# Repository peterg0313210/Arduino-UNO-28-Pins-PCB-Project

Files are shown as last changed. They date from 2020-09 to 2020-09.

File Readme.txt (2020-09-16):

These two folders contain the manufacturing and assembly documentation I produced when I had my circuit board printed and assembled.
Some of the files might need to be downloaded to be viewed such as the Project_1.pdf file which shows the 3D model of my PCB on Adobe Reader. 
However, most of the files should be readily visible upon the initial click to view the file.

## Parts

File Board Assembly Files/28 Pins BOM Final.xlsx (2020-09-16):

 |  |  | Project 1 Arduino 28 Pins BOM
Item # | *Designator | *Qty | Manufacturer | *Mfg Part # | Description / Value | *Package/Footprint | Type | Your Instructions / Notes
1 | SCKT FOR U1 | 1 | 3M | 4828-3004-CP | CONN IC DIP SOCKET 28POS TIN | 28_DIP_7.62MM_ SOCKET | thru-hole
2 | J5, J6 | 2 | Amphenol FCI | 67997-106HLF | CONN HEADER 6POS .100 STR 30AU | HDR 2X3 | thru-hole
3 | JP1, JP4 | 2 | Amphenol FCI | 68000-103HLF | Conn Unshrouded Header HDR 3 POS 2.54mm Solder ST Thru-Hole Bulk | HEADER_1X3_2.54mm | thru-hole | JP4 is Non Fitted
4 | JP3 | 1 | Amphenol FCI | 68001-204HLF | CONN HEADER VERT 4POS 2.54MM | HEADER_1X4 | thru-hole
5 | JP2 | 1 | Amphenol FCI | 68602-204HLF | CONN HEADER VERT 4POS 2.54MM | HDR 2X2_2.54mm | thru-hole | JP2 is Non Fitted
6 | SW1, SW2 | 2 | TE Connectivity | 1825910-6 | Switch Push Button OFF (ON) SPST Round Button 0.05A 24VDC Momentary Contact PC Pins Thru-Hole | 1825910-6 | thru-hole
7 | J7 | 1 | Amphenol FCI | 10118193-0001LF | CONN USB MICRO B RECPT SMT R/A | USB_C | SMD
8 | D5, D6 | 2 | ON Semiconductor / Fairchild | BAT54HT1G | Small Signal Schottky Diode, Single, 30 V, 200 mA, 800 mV, 600 mA, 150 C ;RoHS Compliant: Yes | SOD323 | SMD
9 | Z1, Z2 | 2 | Bourns | CG0603MLC-05E | VARISTOR 0603 | R0603 | SMD
10 | D1 | 1 | Osram Opto | LGL29K-G2J1-24-Z | LED Uni-Color Green 572nm 2-Pin Chip 0603(1608Metric) T/R | LED_0603 | SMD
11 | R, T, U | 3 | Osram Opto | LOL29K-H2K1-24-Z | OSRAM - LO L29K-H2K1-24-Z - SMARTLED 0603 ORANGE | LED_0603 | SMD
12 | C9, C10, C25, C27 | 4 | KEMET | C0805C180J5GACTU | CAP CER 18PF 50V C0G/NP0 0805 | C0805 | SMD
13 | C7 | 1 | TDK | C2012X5R1E105K125AA | TDK - C2012X5R1E105K125AA - SMD Multilayer Ceramic Capacitor, 1 µF, 25 V, 0805 [2012 Metric], ± 10%, X5R, C Series | C0805 | SMD
14 | C3, C12, C13, C20, C21, C23, C34 | 7 | TDK | C2012X5R1V106M125AC | TDK - C2012X5R1V106M125AC - General Purpose / 7" (180mm) | C0805 | SMD
15 | C4, C5, C6, C8, C11, C14, C15, C16, C17, C19, C22, C24, C26, C28, C29, C30, C31, C32, C33 | 19 | TDK | C2012X7R1H104K085AA | TDK - C2012X7R1H104K085AA - SMD Multilayer Ceramic Capacitor, 0.1 µF, 50 V, 0805 [2012 Metric], ± 10%, X7R, C Series | C0805 | SMD
16 | FB1, FB2, FB3 | 3 | TDK | MPZ2012S601AT000 | FERRITE BEAD 600 OHM 0805 1LN | C0805 | SMD
17 | R10, R11, R12 | 3 | Yageo | RC0805FR-071KL | RESISTOR, 0805 1K 1%, FULL REEL; Product Range:YAGEO - RC Series; Resistance:1kohm; Power Rating:125mW; Resistance Tolerance:± 1%; Resistor Case Style:0805 [2012 Metric]; Resistor Element Material:Thick Film; Temperature Coefficient:± 250ppm/°C; Voltage Rating:150V; Packaging:Tape & Reel; MSL:-; SVHC:No SVHC (16-Dec-2013); External Depth:0.55mm; External Length / Height:2mm; External Width:1.25mm; No. of Pins:2; Operating Temperature Max:155°C; Operating Temperature Min:-55°C; Operating Temperature Range:-55°C to +155°C; Reel Quantity:5000; Resistor Mounting:SMD; Series:RC12H; Temperature Coef | R0805 | SMD
18 | R9, R16 | 2 | Yageo | RC0805FR-071ML | RES SMD 1M OHM 1% 1/8W 0805 | R0805 | SMD
19 | R4, R14, R18, R19, R20, R21 | 6 | Yageo | RC0805FR-0710KL | RES SMD 10K OHM 1% 1/8W 0805 | R0805 | SMD
20 | R5, R6, R7, R13, R23, R24, R25 | 7 | Yageo | RC0805FR-0722RL | RES SMD 22 OHM 1% 1/8W 0805 | R0805 | SMD
21 | R1 | 1 | Yageo | RC0805FR-07100KL | YAGEO RC0805FR-07100KL RES, THICK FILM, 100K, 1%, 0.125W, 0805, REEL | R0805 | SMD
22 | R2, R3, R15, R17, R22 | 5 | Yageo | RC0805FR-07560RL | Surface Mount Thick Film Resistor, RC Series, 560 ohm, 125 mW, - 1%, 150 V, 0805 [2012 Metric] | R0805 | SMD
23 | R8, R26, R27, R28 | 4 | Yageo | RC0805JR-070RL | Surface Mount Thick Film Resistor, RC Series, 125 mW, - 5%, 150 V, 0805 [2012 Metric] | R0805 | SMD | R26 and R28 are Non-Fitted
24 | L1 | 1 | KEMET | L1210R2R2MDWIT | FIXED IND 2.2UH 2A 80 MOHM SMD | C1210_IND_1 | SMD
25 | U2 | 1 | Microchip / Atmel | ATMEGA16U2-AU | MICROCHIP - ATMEGA16U2-AU - MCU, 8BIT, MEGAAVR, 16MHZ, TQFP-32 | TQFP32 | SMD
26 | Y1, Y2 | 2 | Abracon | ABM7-16.000MHZ-D2Y-T | CRYSTAL 16.0000MHZ 18PF SMD | ABM7_v1_1_BIG | SMD
27 | U1 | 1 | Microchip / Atmel | ATMEGA328P-PU | ATMEGA328P-PU; 8 bit Microcontroller AVR 20MHz 1; 32kb Flash; 2kb RAM; I2C SPI 2 | DIP28_1 | thru-hole
28 | C1, C2 | 2 | Panasonic | EEE-1AA101WR | Cap Aluminum 100uF 10V 20% (5 X 5.4mm) SMD 50mA 1000 hr 85°C T/R | C_ALU_C_SIZE | SMD
29 | J2 | 1 | Harwin | M20-7820646 | 06-WAY SIL VERT SOCKET L/FREE | FEMALE 6 PIN HEADER | thru-hole
30 | J1, J3 | 2 | Harwin | M20-7820842 | 2.54mm (0.1") Pitch SIL Vertical PC Tail Socket Assembly, selective gold + tin, 8 contacts | HEADER_8 | thru-hole
31 | J4 | 1 | Harwin | M20-7821046 | HARWIN - M20-7821046 - Board-To-Board Connector , M20 Series, Through Hole, Receptacle, 10, 2.54 mm, Tin Plated Contacts | FEMALE_HEADER | thru-hole
32 | U4, U5, U6, U7 | 4 | Texas Instruments | SN74AHC1G09DBVR | TEXAS INSTRUMENTS - SN74AHC1G09DBVR - AND Gate, 74AHC1G09, 2 Input, 2 V to 5.5 V, SOT-23-5 | DBV_SOT_23_5 | SMD
33 | U3 | 1 | Texas Instruments | TL1963A-33DCQR | IC REG LINEAR 3.3V 1.5A SOT223-6 | DCQ (R-PDSO-G6) | SMD

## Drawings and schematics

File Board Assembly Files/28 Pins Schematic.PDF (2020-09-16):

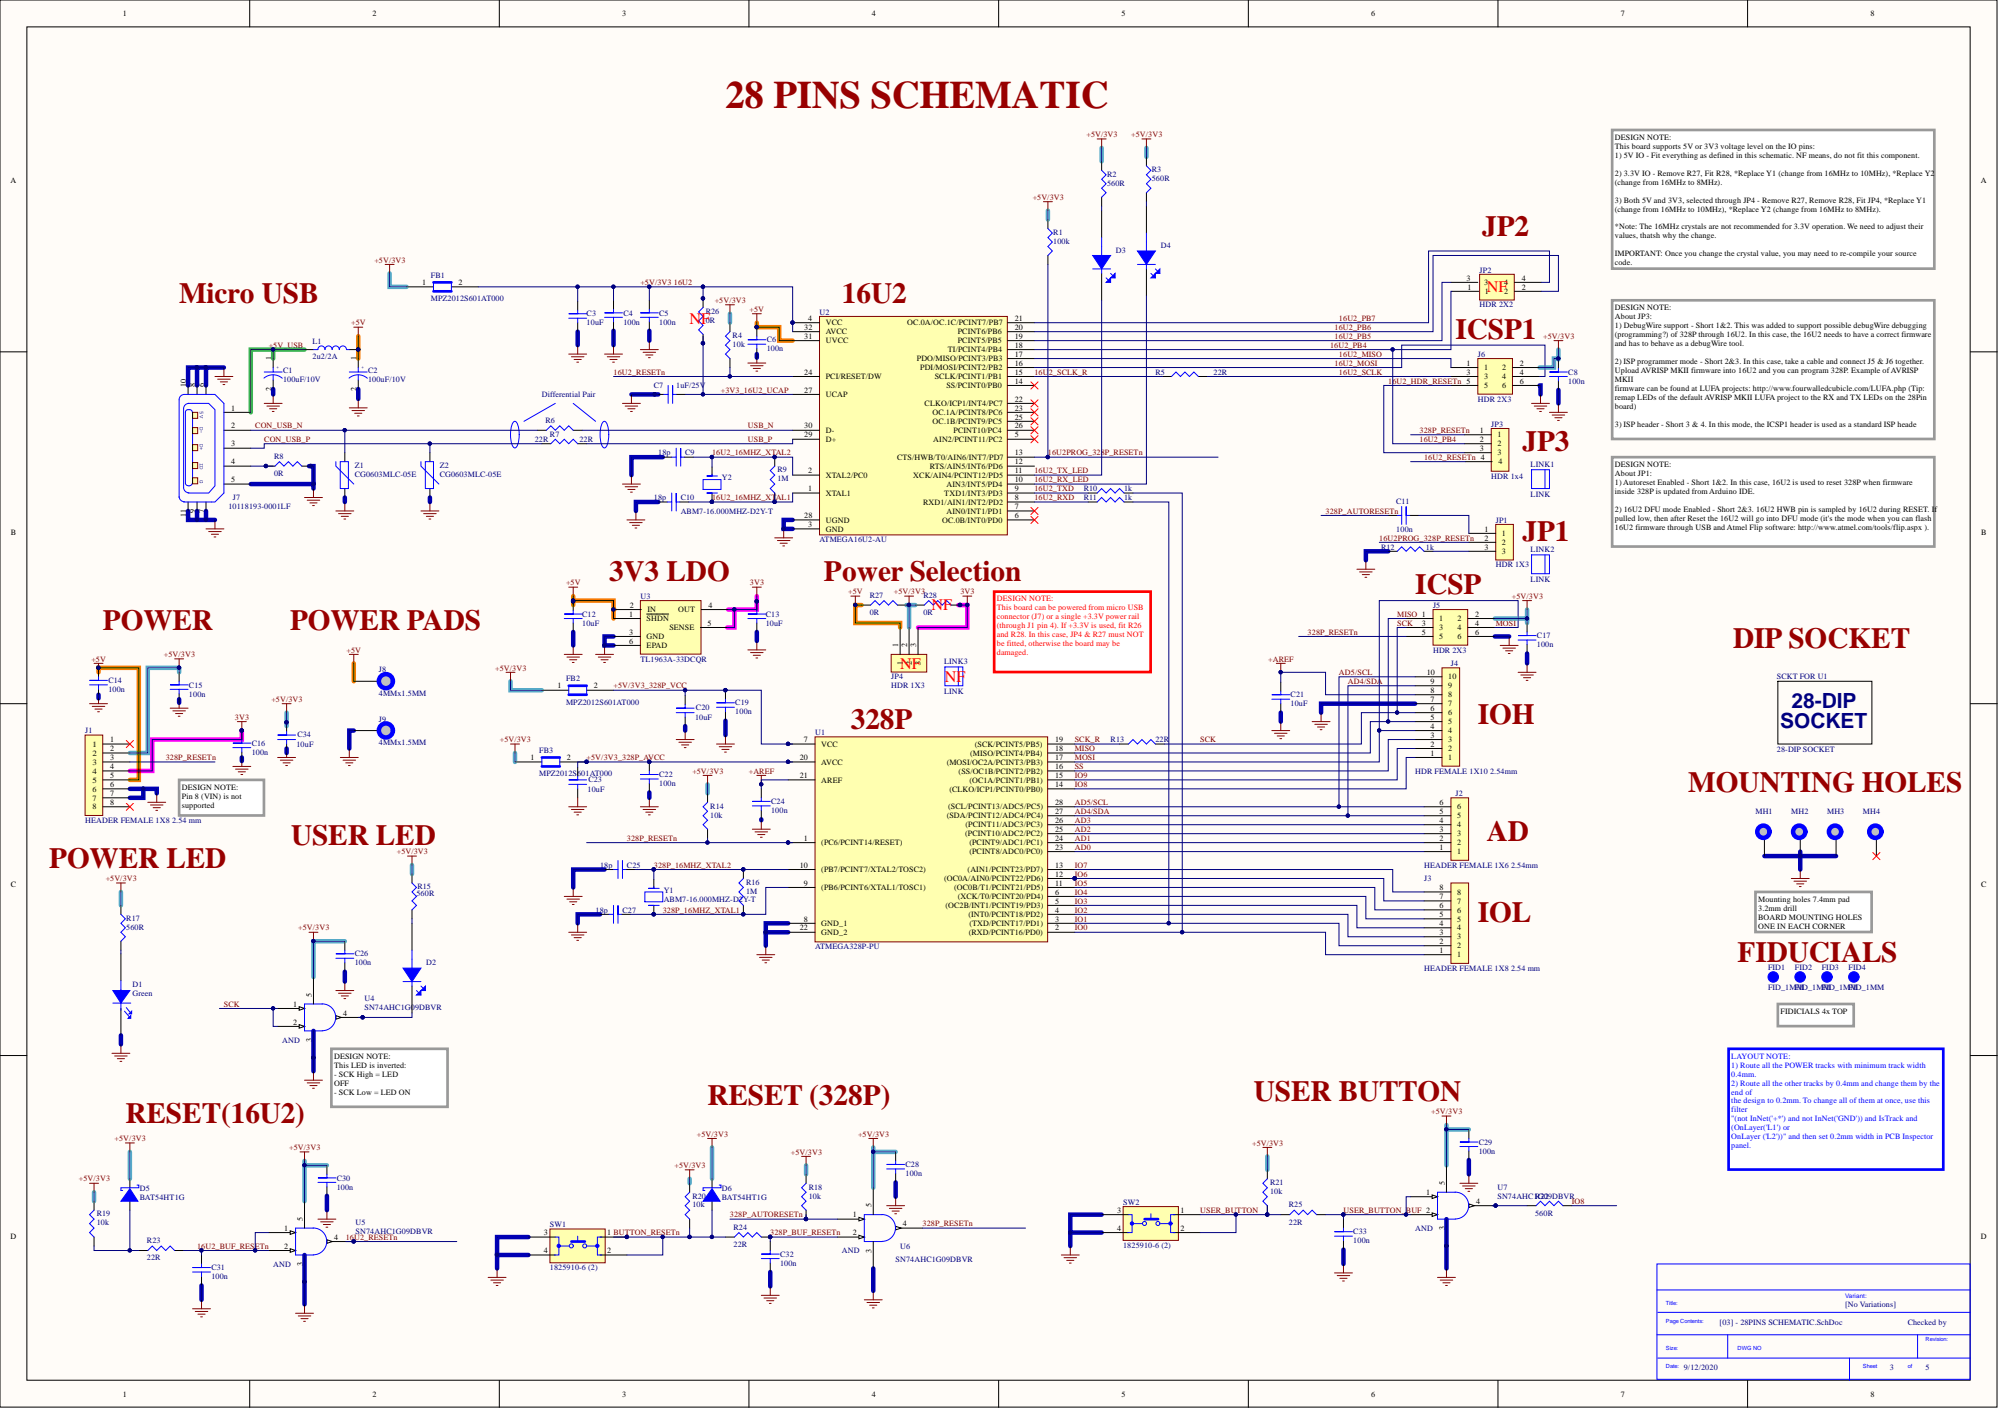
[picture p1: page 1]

DESIGN NOTE:
This board supports 5V or 3V3 voltage level on the IO pins:
1) 5V IO - Fit everything as defined in this schematic. NF means, do not fit this component.

2) 3.3V IO - Remove R27, Fit R28, *Replace Y1 (change from 16MHz to 10MHz), *Replace Y2
(change from 16MHz to 8MHz).

3) Both 5V and 3V3, selected through JP4 - Remove R27, Remove R28, Fit JP4, *Replace Y1
(change from 16MHz to 10MHz), *Replace Y2 (change from 16MHz to 8MHz).

*Note: The 16MHz crystals are not recommended for 3.3V operation. We need to adjust their
values, thatsh why the change.

IMPORTANT: Once you change the crystal value, you may need to re-compile your source
code.

About JP3:
1) DebugWire support - Short 1&2. This was added to support possible debugWire debugging
(programming?) of 328P through 16U2. In this case, the 16U2 needs to have a correct firmware
and has to behave as a debugWire tool.

2) ISP programmer mode - Short 2&3. In this case, take a cable and connect J5 & J6 together.
Upload AVRISP MKII firmware into 16U2 and you can program 328P. Example of AVRISP
MKII
firmware can be found at LUFA projects: http://www.fourwalledcubicle.com/LUFA.php (Tip:
remap LEDs of the default AVRISP MKII LUFA project to the RX and TX LEDs on the 28Pin
board)

3) ISP header - Short 3 & 4. In this mode, the ICSP1 header is used as a standard ISP heade

About JP1:
1) Autoreset Enabled - Short 1&2. In this case, 16U2 is used to reset 328P when firmware
inside 328P is updated from Arduino IDE.

2) 16U2 DFU mode Enabled - Short 2&3. 16U2 HWB pin is sampled by 16U2 during RESET. If
pulled low, then after Reset the 16U2 will go into DFU mode (it's the mode when you can flash
16U2 firmware through USB and Atmel Flip software: http://www.atmel.com/tools/flip.aspx ).

This board can be powered from micro USB
connector (J7) or a single +3.3V power rail
(through J1 pin 4). If +3.3V is used, fit R26
and R28. In this case, JP4 & R27 must NOT
be fitted, otherwise the board may be
damaged.

AD4/SDA

AREF 21 | SS

Pin 8 (VIN) is not
supported

AD5/SCL

AD2
AD1

(PB7/PCINT7/XTAL2/TOSC2) 10 | AD0

Mounting holes 7.4mm pad
3.2mm drill
BOARD MOUNTING HOLES
ONE IN EACH CORNER
FIDUCIALS

IO2
IO1

GND_1 8
GND_2 22 | IO0

This LED is inverted:
- SCK High = LED
OFF
- SCK Low = LED ON

LAYOUT NOTE:
1) Route all the POWER tracks with minimum track width
2) Route all the other tracks by 0.4mm and change them by the
end of
the design to 0.2mm. To change all of them at once, use this
filter
"(not InNet('+*') and not InNet('GND')) and IsTrack and
(OnLayer('L1') or
OnLayer ('L2'))" and then set 0.2mm width in PCB Inspector
panel.

Size: | DWG NO | Revision:

Date: 9/12/2020 | Sheet 3 of 5

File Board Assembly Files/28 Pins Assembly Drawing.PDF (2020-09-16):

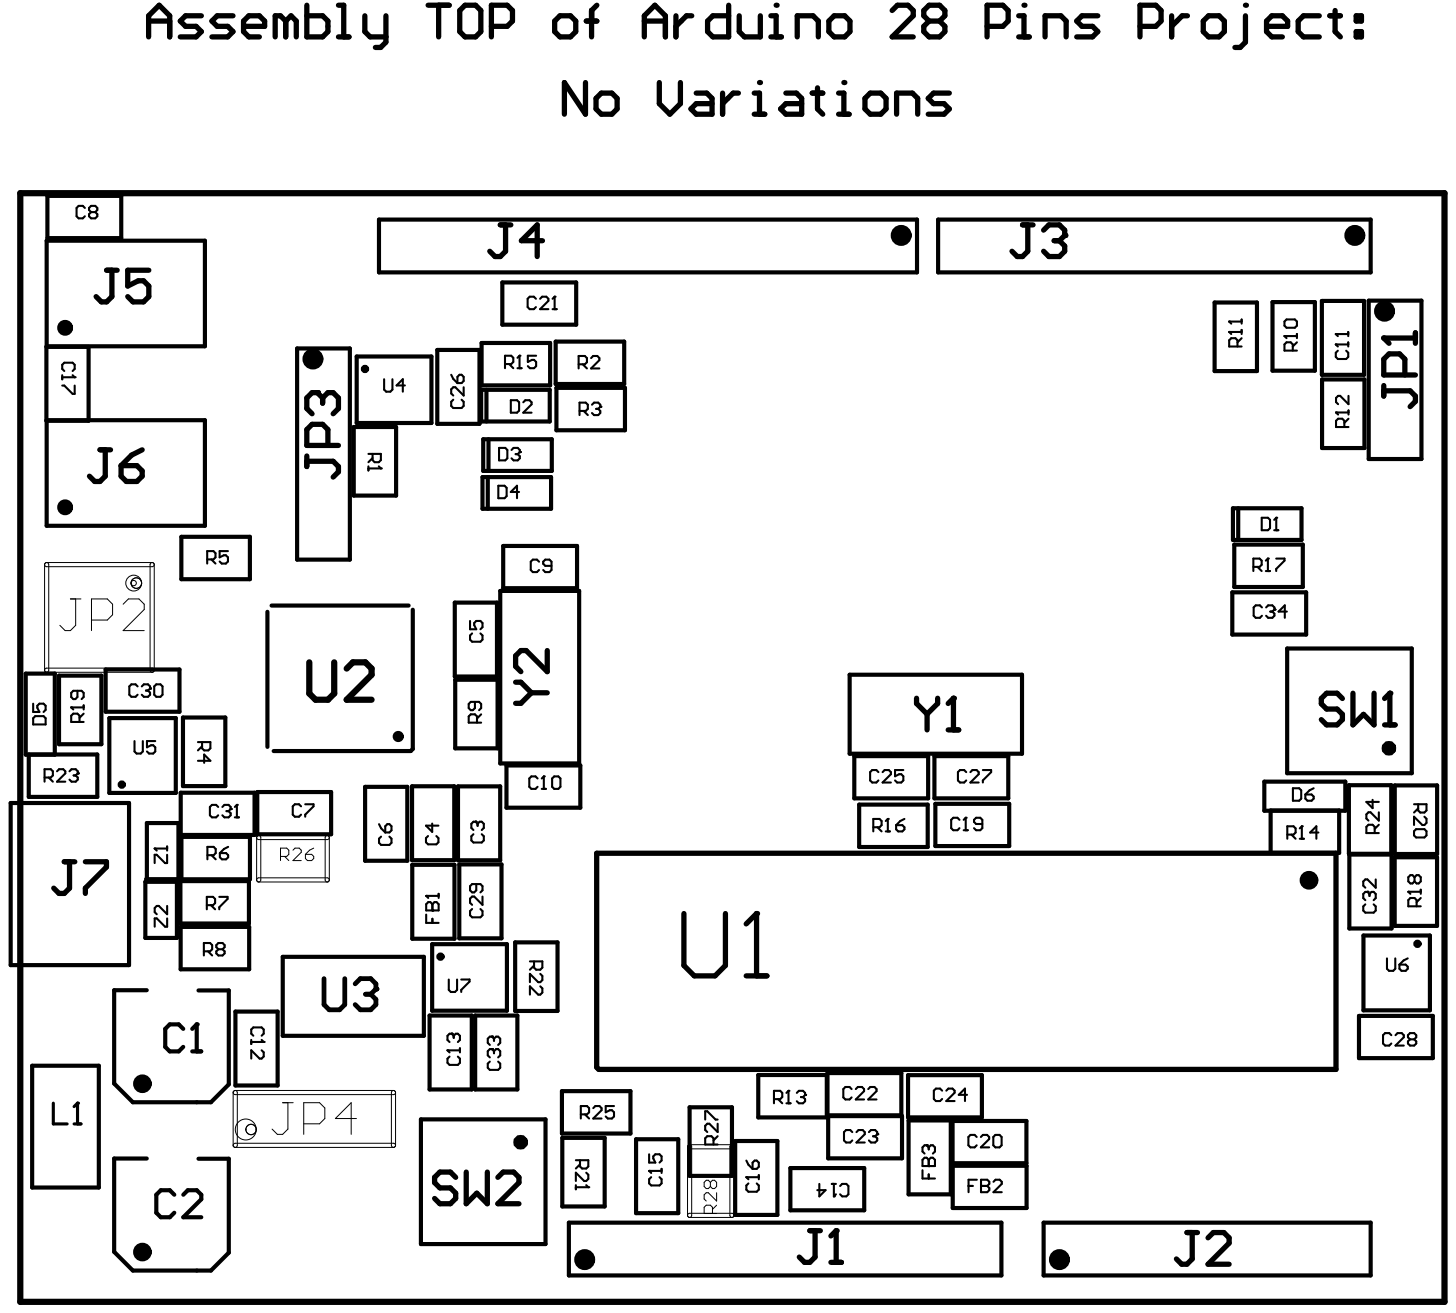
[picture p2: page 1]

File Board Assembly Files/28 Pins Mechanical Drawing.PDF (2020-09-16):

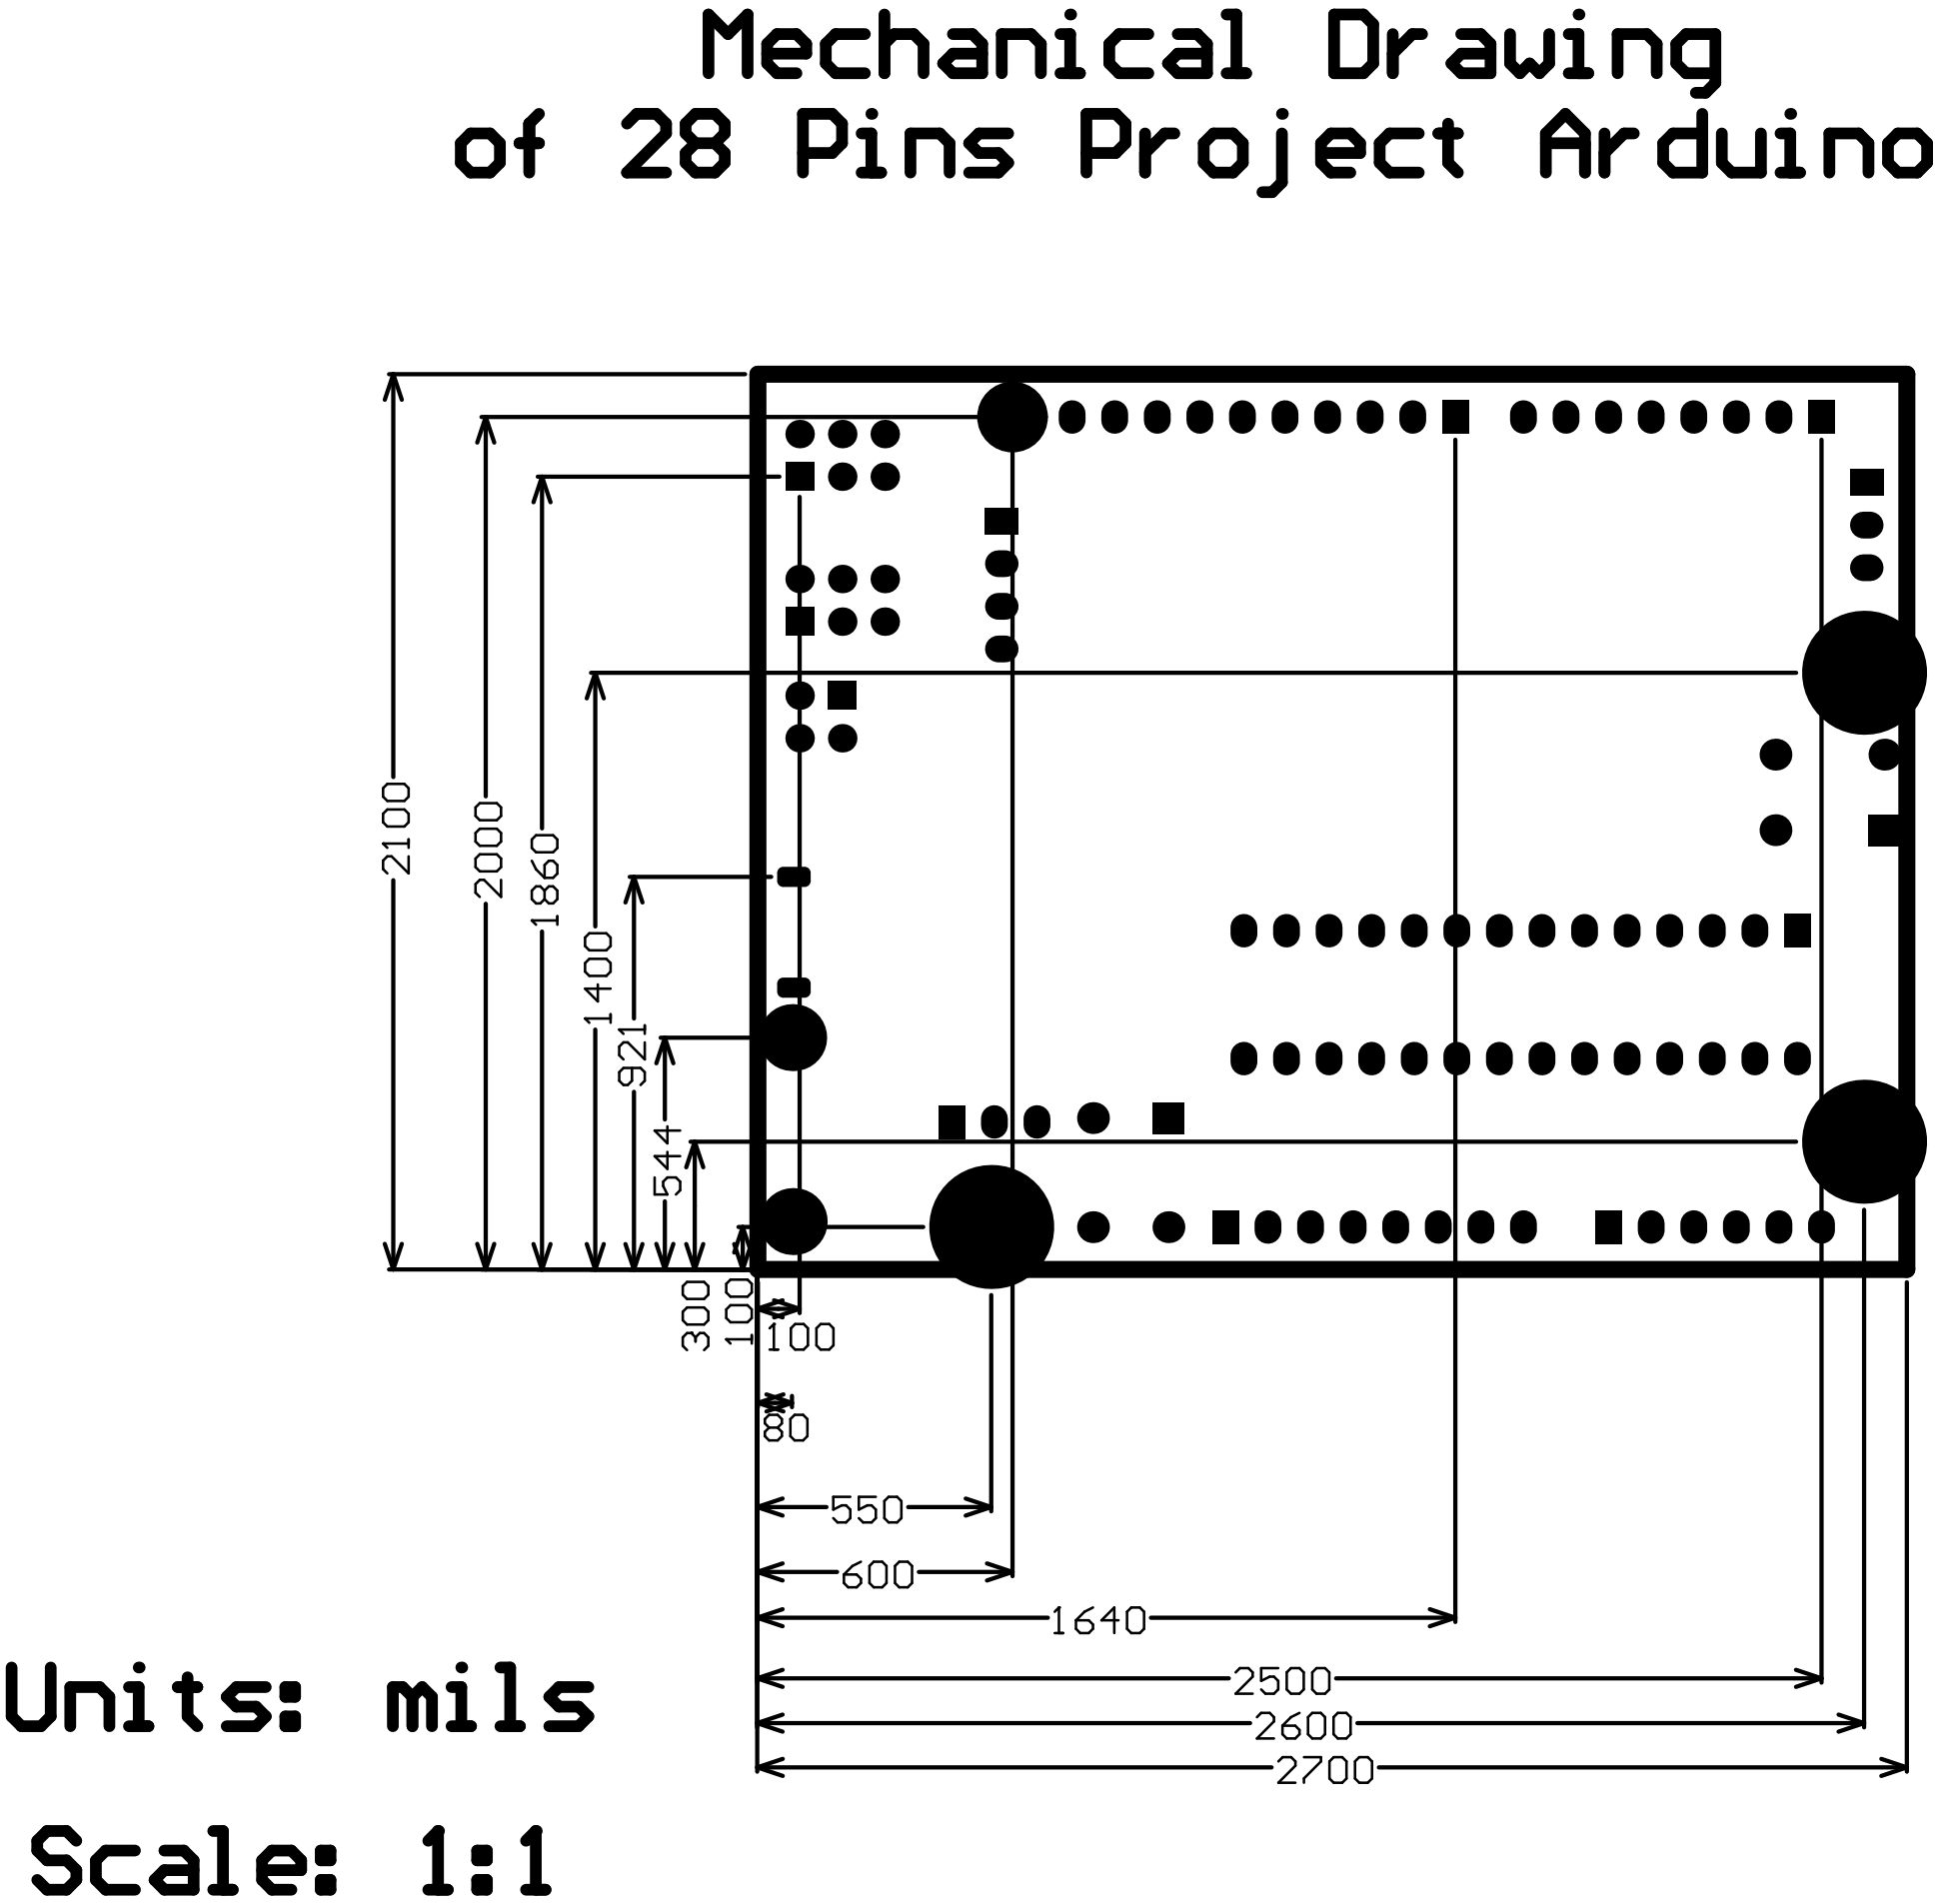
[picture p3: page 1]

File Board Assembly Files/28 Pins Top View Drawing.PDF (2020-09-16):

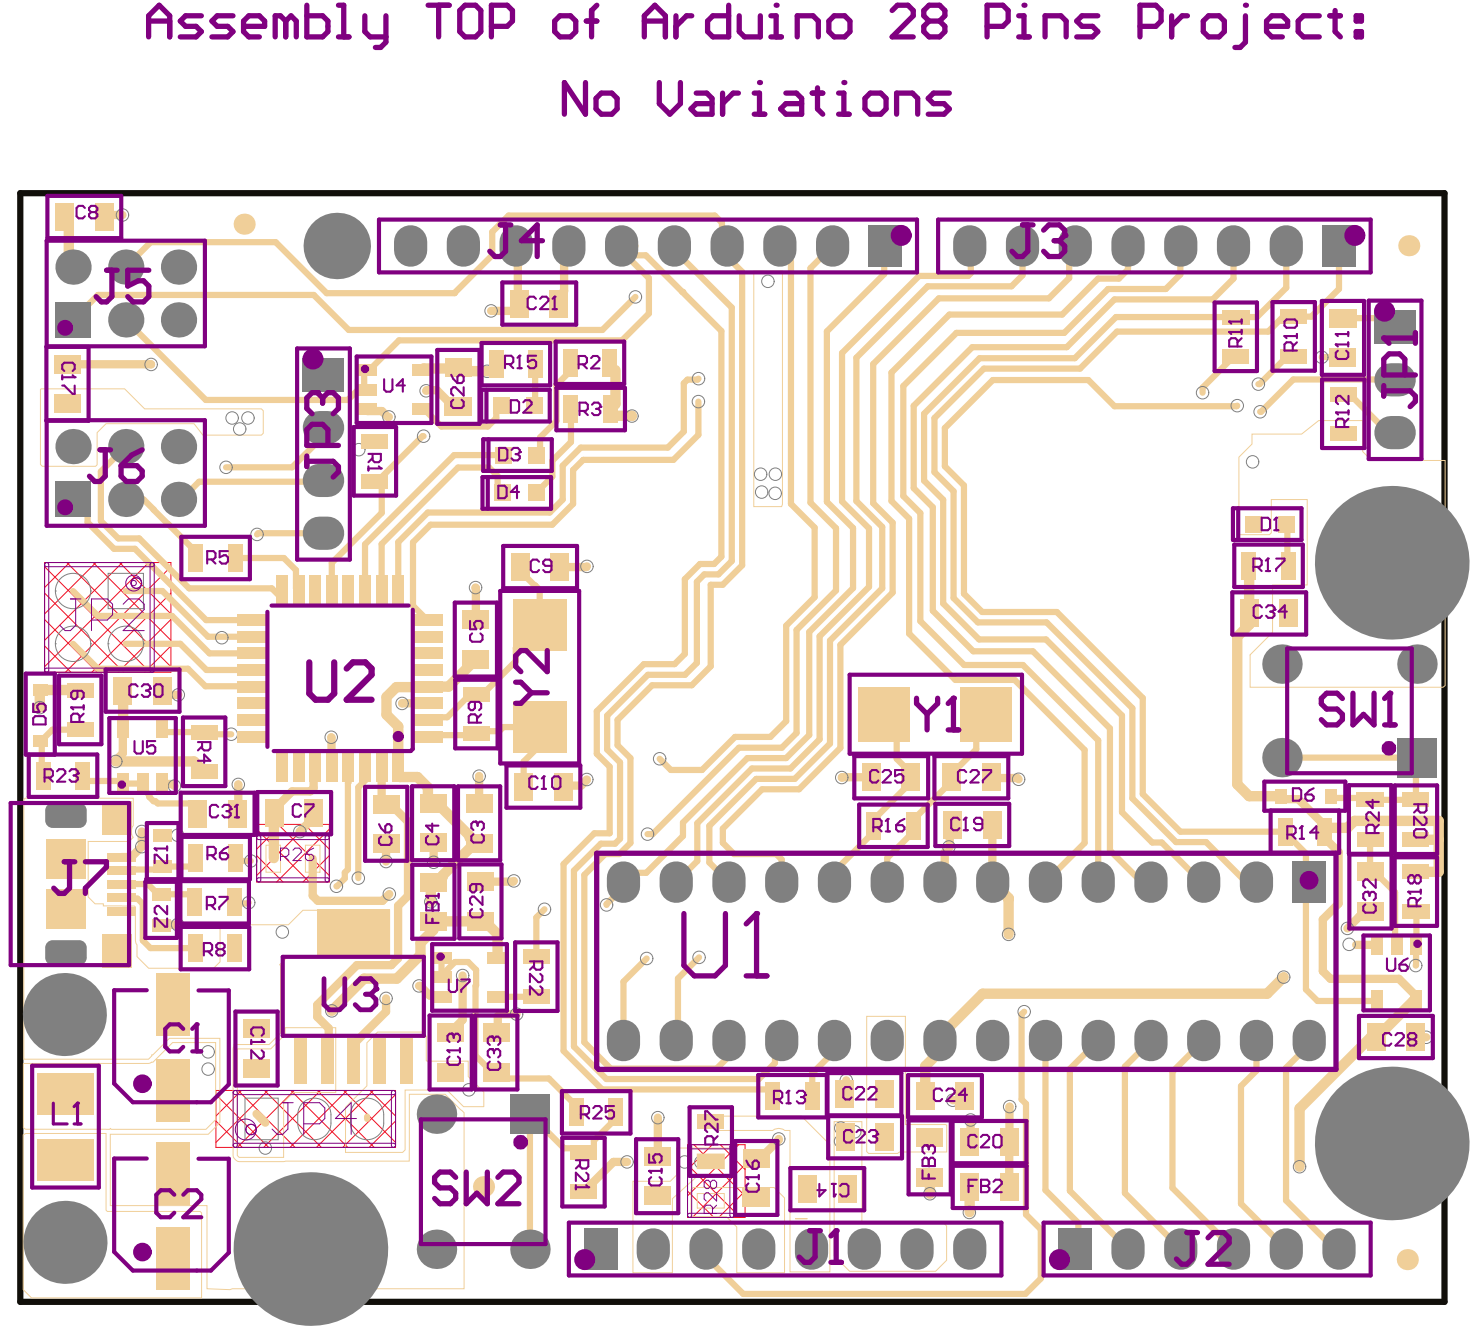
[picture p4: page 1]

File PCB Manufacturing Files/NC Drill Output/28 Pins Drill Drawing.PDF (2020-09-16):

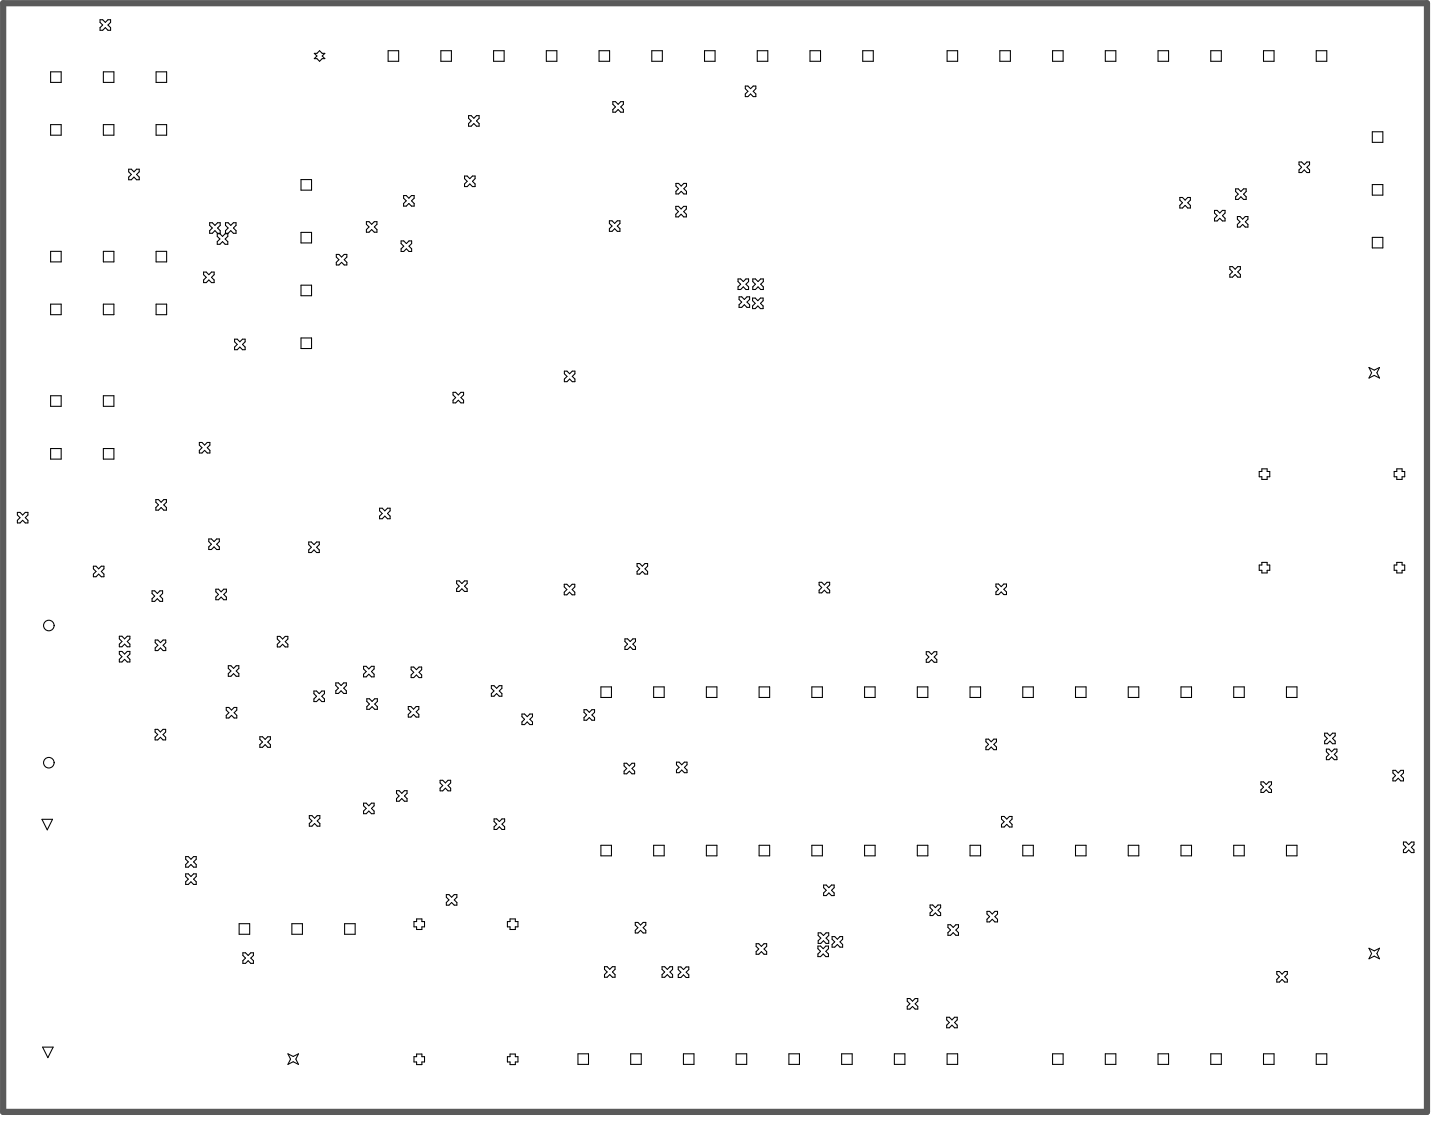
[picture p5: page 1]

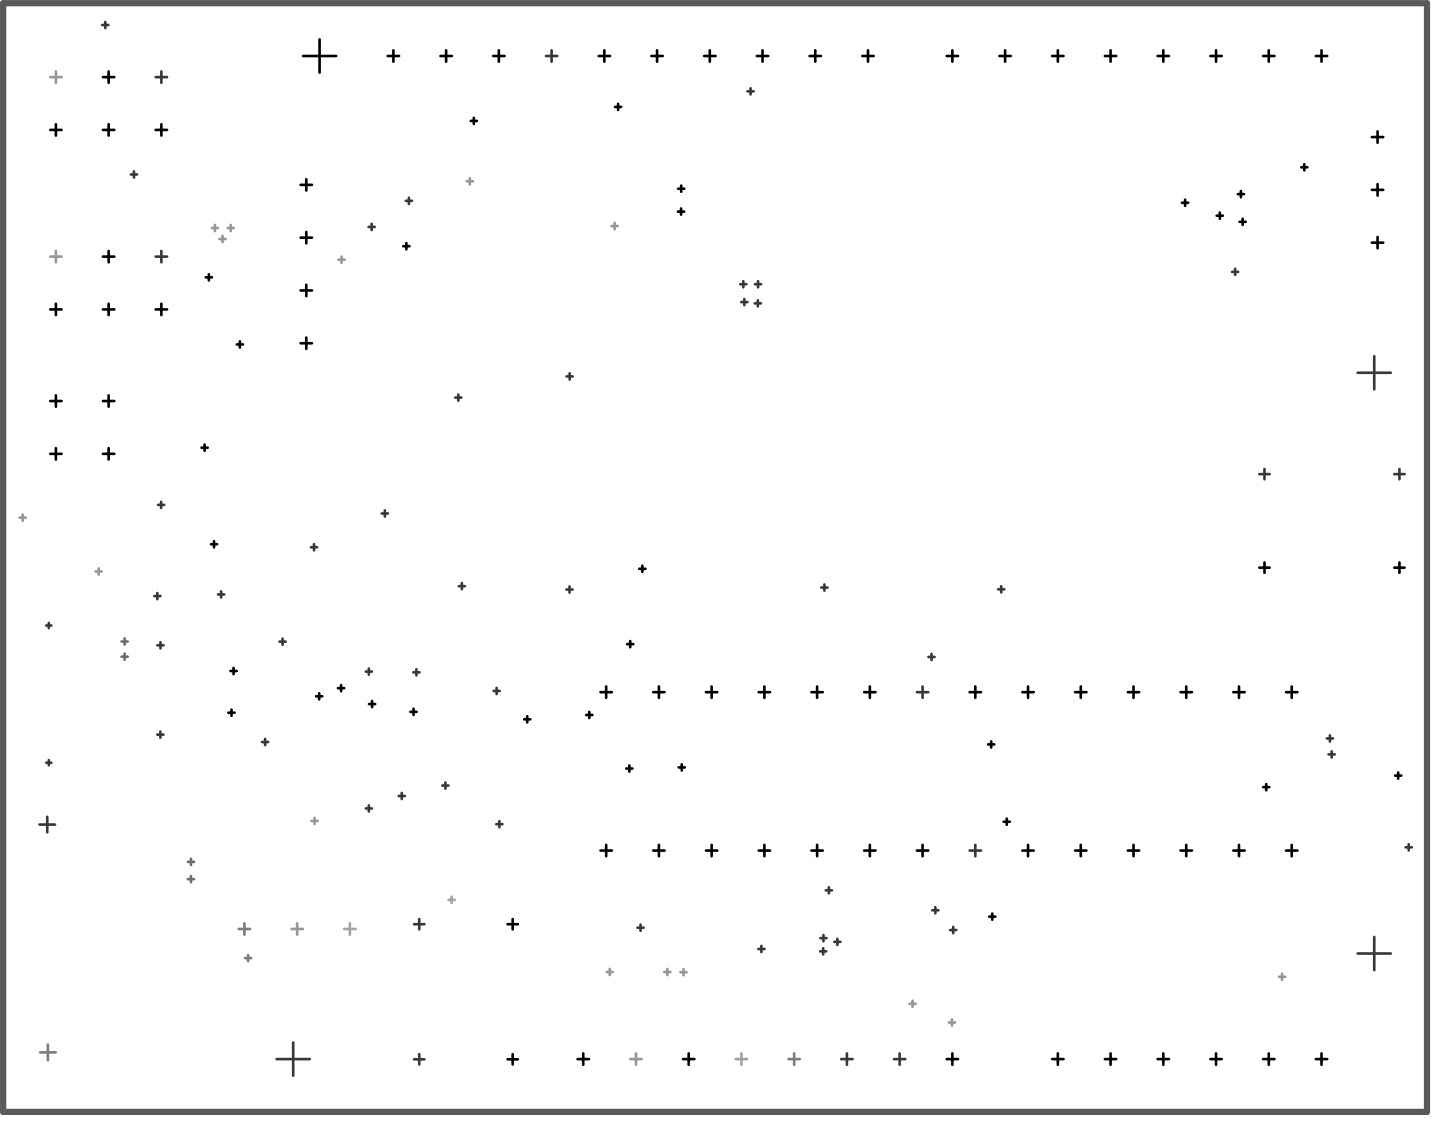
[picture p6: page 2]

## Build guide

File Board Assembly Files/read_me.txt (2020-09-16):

Place following files here:

- Mechanical Drawing (Board dimensions, holes position, ..)
- TOP and BOTTOM Assembly Drawing (Component position with Reference Designator)
- TOP and BOTTOM VIEW (shows board outline, assembly layer, TOP + BOTTOM layers)
- Bill of Materials (grouped by component type)
- Component reference BOM (each component on one line: Designator, Description, Manufacturer 1,
  Manufacturer, Part Number 1, Package / Case, Supplier 1, Supplier Part Number 1)
- Component reference BOM (as above) grouped by component type.
- Pick and Place
- TOP and BOTTOM Layer + TOP and BOTTOM Paste Gerber Files (for stencil - if panel is done in a PCB house, ask them later for the top/bottom layers and paste for the panel)
- PDF 3D Model

!!! BE AWARE !!! If you use a VARIANT were you replace a component by other component,
THIS WILL NOT BE REFLECTED IN ASSEMBLY DRAWING and component will look like not fitted.
This may be a bug in Altium 14.3. Use a TEMP Schematic to generate the ASM DRWG. SAME
FOR PICK & PLACE!!

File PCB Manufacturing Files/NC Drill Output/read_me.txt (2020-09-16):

Place here drill files and documents which explain it (e.g. for HDI PCB you can put here pdf showing drills for each layer pair)
